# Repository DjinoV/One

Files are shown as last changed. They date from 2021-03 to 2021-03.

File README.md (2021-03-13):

# One
 A tiny model rocket flight computer and data logger.
 
 It features:
 - A STM32F103C8T6
 - A BMI088 IMU
 - A BMP280 Barometric pressure sensor
 - A microSD card slot
 - A 32MB flash chip
 - A single pyro channel 
 - Micro USB
 - And ofcourse, a single RGB LED

 Board size:
 50(maybe 40)x30mm
 Powered off a 12V Li-Po

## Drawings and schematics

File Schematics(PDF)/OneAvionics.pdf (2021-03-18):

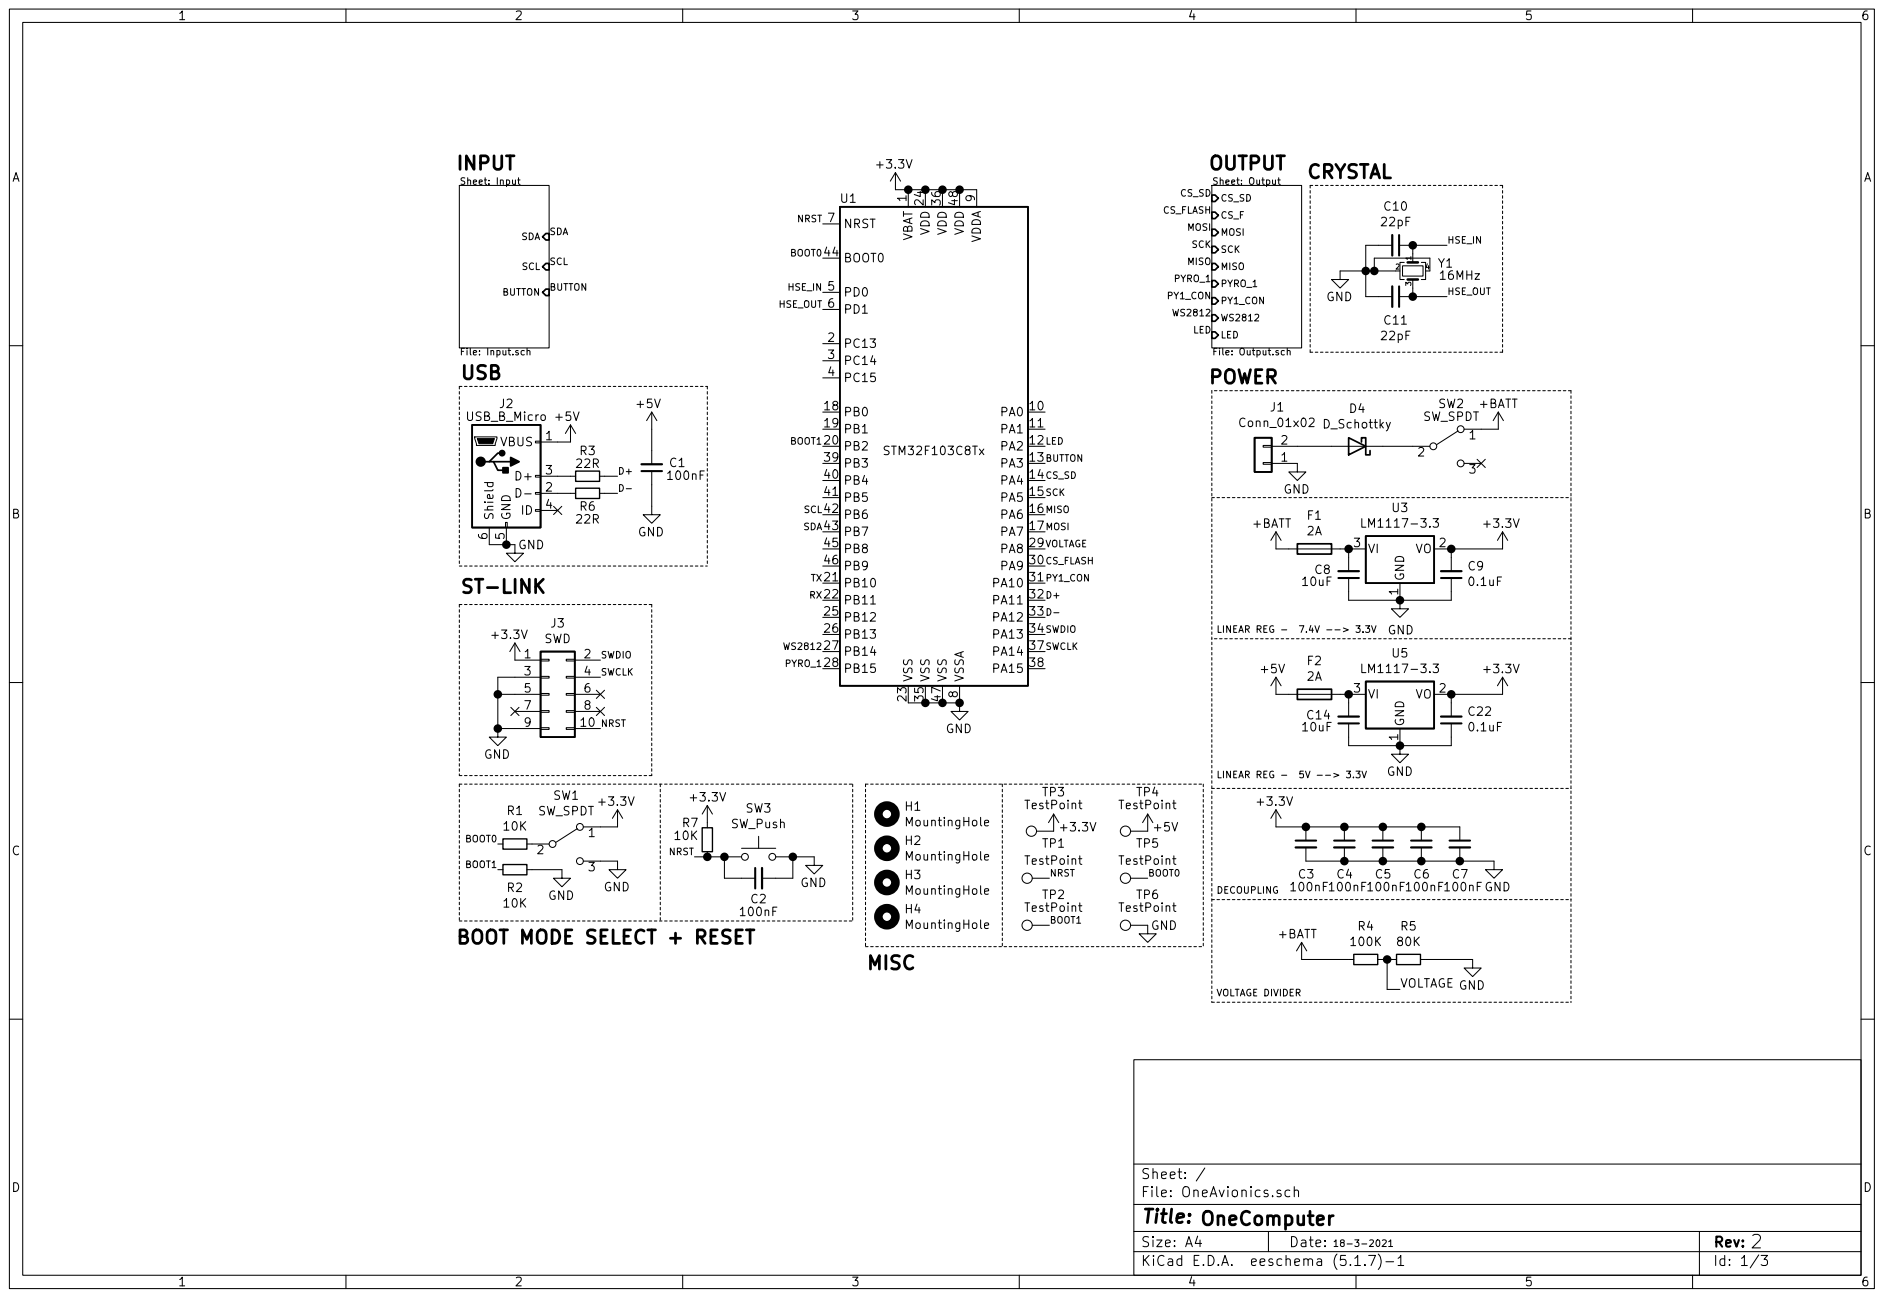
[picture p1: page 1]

INPUT
Sheet: Input File: Input.sch BUTTON

OUTPUT
Sheet: Output File: Output.sch MOSI SCK MISO
PYRO_1 CS_SD
LED WS2812 CS_F CS_SD
PY1_CON
LINEAR REG - 7.4V --> 3.3V POWER

BOOT MODE SELECT + RESET

Id: 1/3 Title: File: OneAvionics.sch Sheet: /

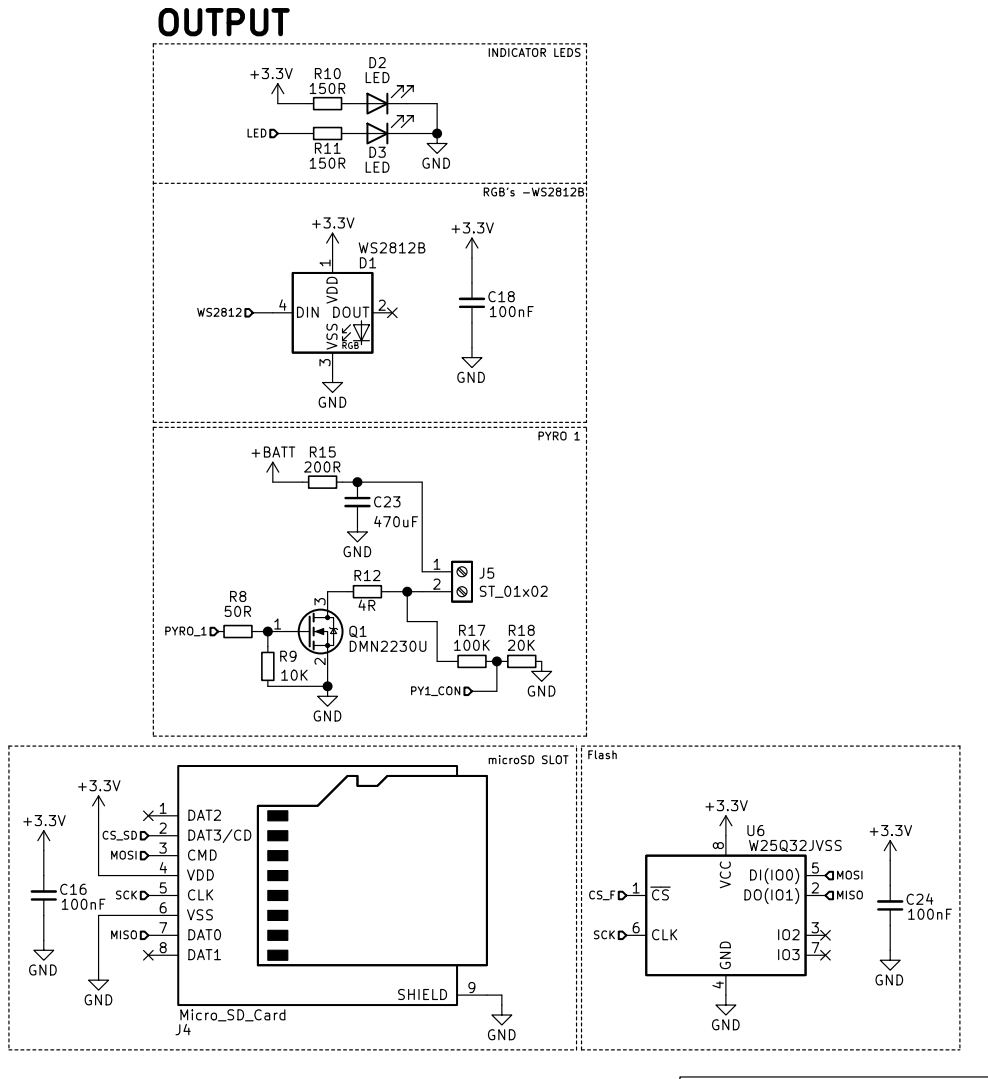
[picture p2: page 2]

PYRO 1 microSD SLOT OUTPUT

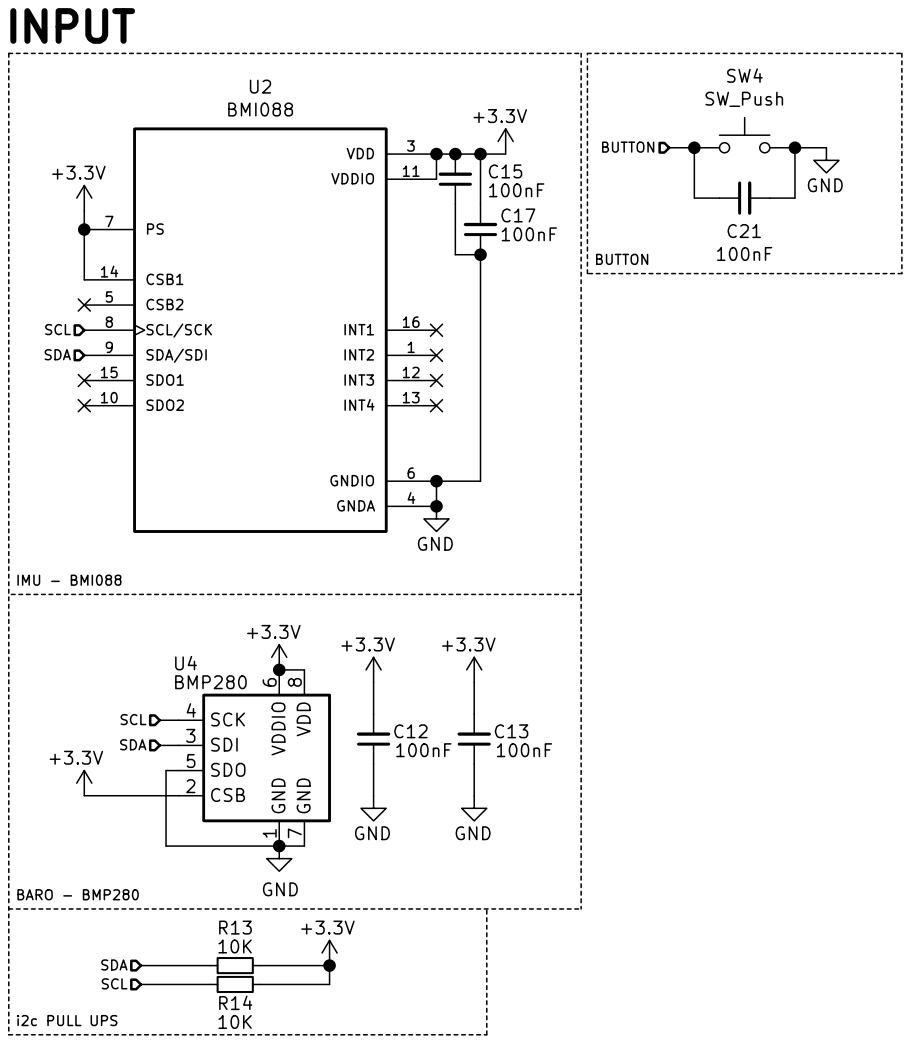
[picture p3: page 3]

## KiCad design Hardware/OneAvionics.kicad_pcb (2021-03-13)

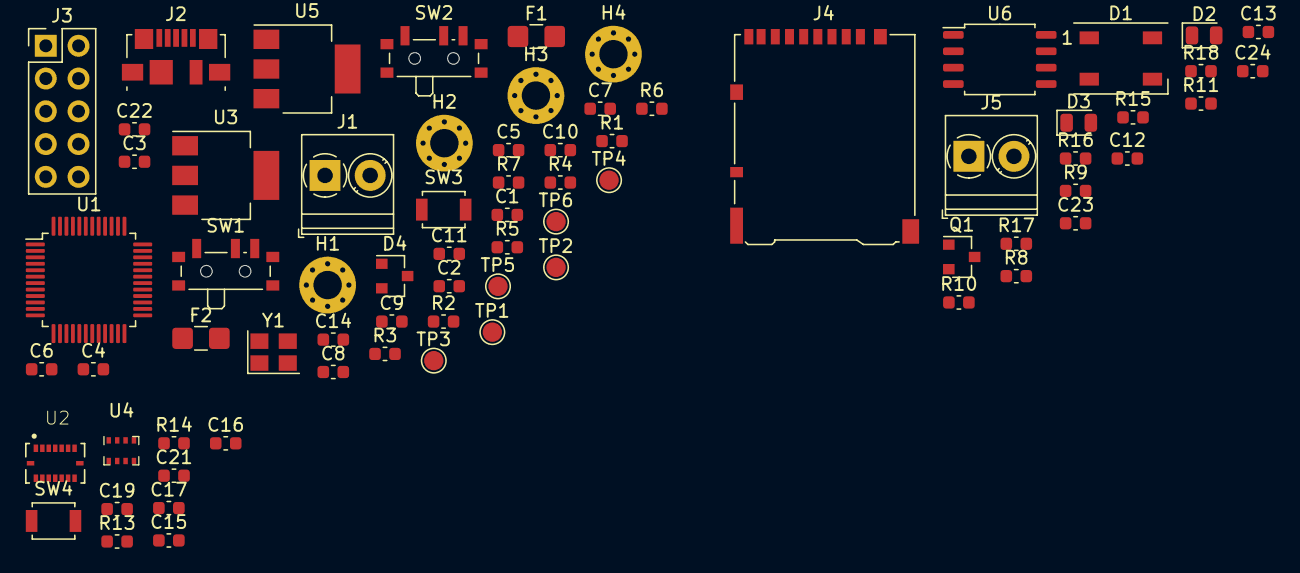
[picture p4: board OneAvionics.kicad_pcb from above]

Board: 2 copper layers, 72 parts (0 on the bottom side), 37 nets, no tracks yet.

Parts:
C1, C2, C3, C4, C5, C6, C7, C12, C13, C15, C16, C17, C19, C21, C24: 100nF; C_0603_1608Metric
C8, C14: 10uF; C_0603_1608Metric
C9, C22: 0.1uF; C_0603_1608Metric
C10, C11: 22pF; C_0603_1608Metric
C23: 470uF; C_0603_1608Metric
D1: WS2812B; LED_WS2812B_PLCC4_5.0x5.0mm_P3.2mm
D2, D3: LED; LED_0805_2012Metric
D4: D_Schottky; SOT-23
F1, F2: 2A; Fuse_1206_3216Metric_Castellated
H1, H2, H3, H4: MountingHole; MountingHole_2.2mm_M2_Pad_Via
J1: Conn_01x02; TerminalBlock_Phoenix_PT-1,5-2-3.5-H_1x02_P3.50mm_Horizontal
J2: USB_B_Micro; USB_Micro-B_Molex_47346-0001
J3: SWD; PinHeader_2x05_P2.54mm_Vertical
J4: Micro_SD_Card; microSD_HC_Hirose_DM3AT-SF-PEJM5
J5: ST_01x02; TerminalBlock_Phoenix_PT-1,5-2-3.5-H_1x02_P3.50mm_Horizontal
Q1: DMN2230U; SOT-23
R1, R2, R7, R9, R13, R14: 10K; C_0603_1608Metric
R3, R6: 22R; C_0603_1608Metric
R4, R17: 100K; C_0603_1608Metric
R5: 38K; C_0603_1608Metric
R8, R10, R11: 150R; C_0603_1608Metric
R15: 200R; C_0603_1608Metric
R16: 5R; C_0603_1608Metric
R18: 20K; C_0603_1608Metric
SW1, SW2: SW_SPDT; SW_SPDT_PCM12
SW3, SW4: SW_Push; SW_SPST_B3U-1000P
TP1, TP2, TP3, TP4, TP5, TP6: TestPoint; TestPoint_Pad_D1.5mm
U1: STM32F103C8Tx; LQFP-48_7x7mm_P0.5mm
U2: BMI088; PQFN50P450X300X100-16N
U3, U5: LM1117-3.3; SOT-223
U4: BMP280; Bosch_LGA-8_2x2.5mm_P0.65mm_ClockwisePinNumbering
U6: W25Q32JVSS; SOIC-8_5.23x5.23mm_P1.27mm
Y1: 16MHz; Crystal_SMD_3225-4Pin_3.2x2.5mm

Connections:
+3V3: C3.1, C4.1, C5.1, C6.1, C7.1, C9.2, C12.2, C13.2, C15.2, C16.1, C17.2, C19.2, C22.2, C24.2, D1.1, J3.1, J4.4, R7.1, R10.2, R13.1, R14.1, SW1.1, TP3.1, U1.1, U1.9, U1.24, U1.36, U1.48, U2.3, U2.7, U2.11, U2.14, U3.2, U4.2, U4.6, U4.8, U5.2, U6.8
+5V: C1.2, F2.2, J2.1, TP4.1
+12V: F1.2, R4.2, R15.2, SW2.1
/BOOT0: R1.2, TP5.1, U1.44
/BOOT1: R2.2, TP2.1, U1.20
/BUTTON: C21.1, SW4.1, U1.13
/D+: R3.1, U1.32
/D-: R6.1, U1.33
/HSE_IN: C10.1, U1.5, Y1.1
/HSE_OUT: C11.1, U1.6, Y1.3
/LED: R11.2, U1.12
/MISO: J4.7, U1.16, U6.2
/MOSI: J4.3, U1.17, U6.5
/NRST: C2.1, J3.10, R7.2, SW3.1, TP1.1, U1.7
/Output/PYRO_CONT: R17.2, R18.1
/PYRO_1: R8.2, U1.28
/RGB: D1.4, U1.27
/SCK: J4.5, U1.15, U6.6
/SCL: R14.2, U1.42, U2.8, U4.4
/SDA: R13.2, U1.43, U2.9, U4.3
/SWCLK: J3.4, U1.37
/SWDIO: J3.2, U1.34
/VOLTAGE: R4.1, R5.2, U1.29
GND: C1.1, C2.2, C3.2, C4.2, C5.2, C6.2, C7.2, C8.1, C9.1, C10.2, C11.2, C12.1, C13.1, C14.1, C15.1, C16.2, C17.1, C19.1, C21.2, C22.1, C23.1, C24.1, D1.3, D2.1, D3.1, J1.2, J2.5, J2.6, J3.3, J3.5, J3.9, J4.6, J4.9, R2.1, R5.1, R9.2, R16.2, R18.2, SW1.3, SW3.2, SW4.2, TP6.1, U1.8, U1.23, U1.35, U1.47, U2.4, U2.6, U3.1, U4.1, U4.5, U4.7, U5.1, U6.4, Y1.2, Y1.4
unnamed: C8.2, F1.1, U3.3
unnamed: C14.2, F2.1, U5.3
unnamed: C23.2, J5.1, R15.1
unnamed: D2.2, R10.1
unnamed: D3.2, R11.1
unnamed: D4.1, SW2.2
unnamed: D4.2, J1.1
unnamed: J2.2, R6.2
unnamed: J2.3, R3.2
unnamed: J5.2, Q1.3, R17.1
unnamed: Q1.1, R8.1, R9.1
unnamed: Q1.2, R16.1
unnamed: R1.1, SW1.2

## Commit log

2021-03-10 rc and cont on pyro, linear reg, flash
    [Input.sch, OneAvionics.sch, Output.sch]
2021-03-10 bno055 removed, bmi088, schotksy
    [Input.sch, OneAvionics.kicad_pcb, OneAvionics.sch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]
2021-03-13 Schematic cleanup, pyro
    thanks ben for the advice
    [Input.sch, OneAvionics.sch, Output.sch]
2021-03-14 more cleanup
    [Input.sch, OneAvionics.kicad_pcb, OneAvionics.sch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]
2021-03-14 MOAR CLEANUP
    [Input.sch, OneAvionics.sch]
2021-03-18 added pdf
    [Input.sch, OneAvionics.kicad_pcb, OneAvionics.sch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]
